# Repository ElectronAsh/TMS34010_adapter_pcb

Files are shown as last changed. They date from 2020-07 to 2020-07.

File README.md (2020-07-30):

# TMS34010_adapter_pcb

# USE AT YOUR OWN RISK!

This adapter PCB should allow you to connect a TMS34010 CPU to FPGA dev boards like the DE10 Nano, and maybe the DE0.

But it is currently UNTESTED, and does not include proper voltage translation buffers between 3V3 and 5V.

The current design only has some series resistors on each CPU output pin, with some clamp diodes on the FPGA GPIO headers.

There is an inherent risk of not using proper voltage translation, but I would personally risk it for short-term use for development.

If I get time, I will add proper voltage translation to the board.
The current design was just a way to get a quick version done for the few devs who might be able to make use of it.

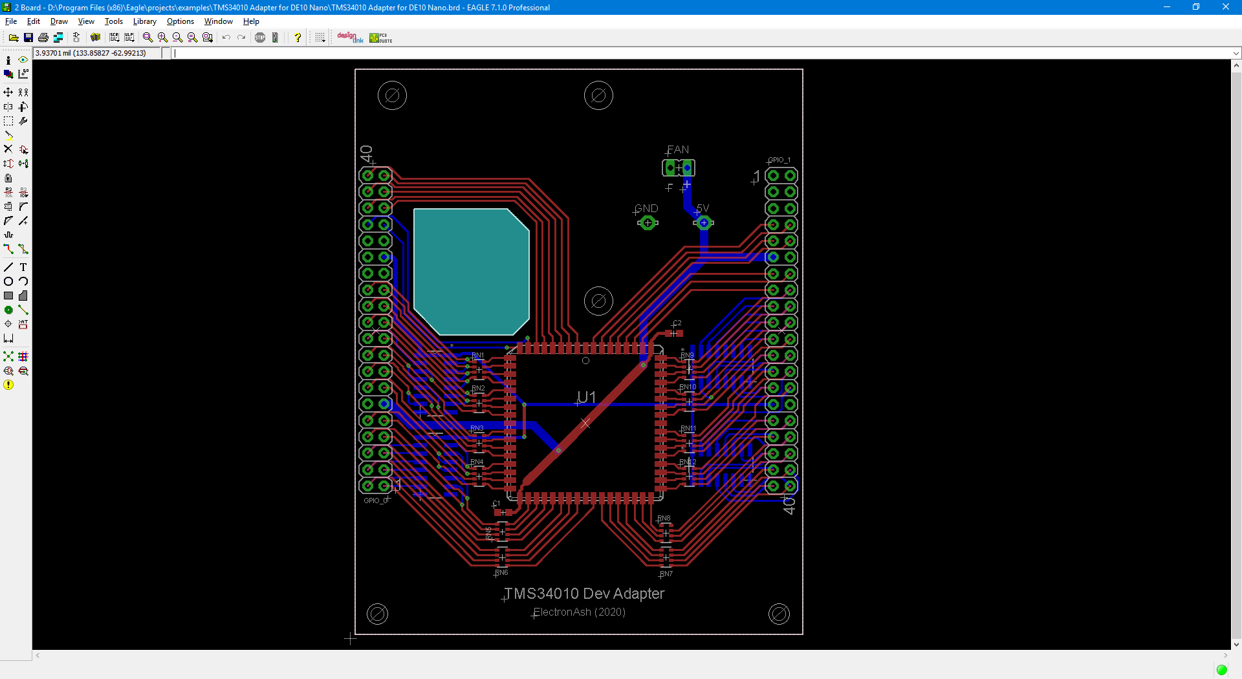
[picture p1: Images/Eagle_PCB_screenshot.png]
Eagle PCB screenshot


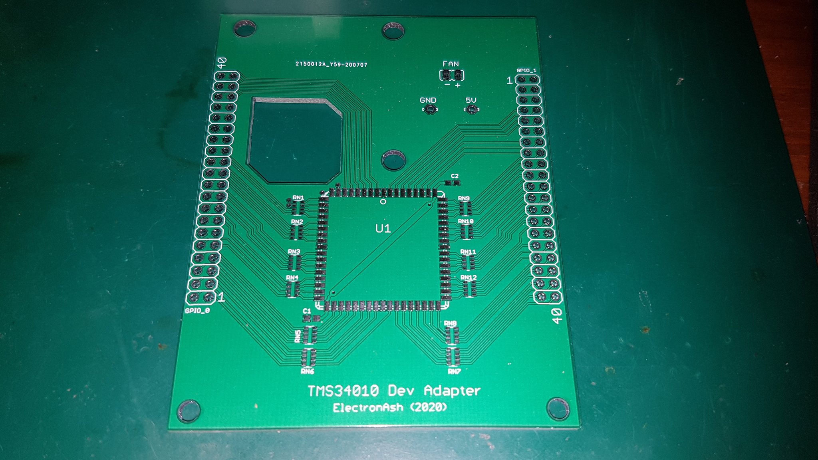
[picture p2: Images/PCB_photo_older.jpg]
PCB photo, older proto


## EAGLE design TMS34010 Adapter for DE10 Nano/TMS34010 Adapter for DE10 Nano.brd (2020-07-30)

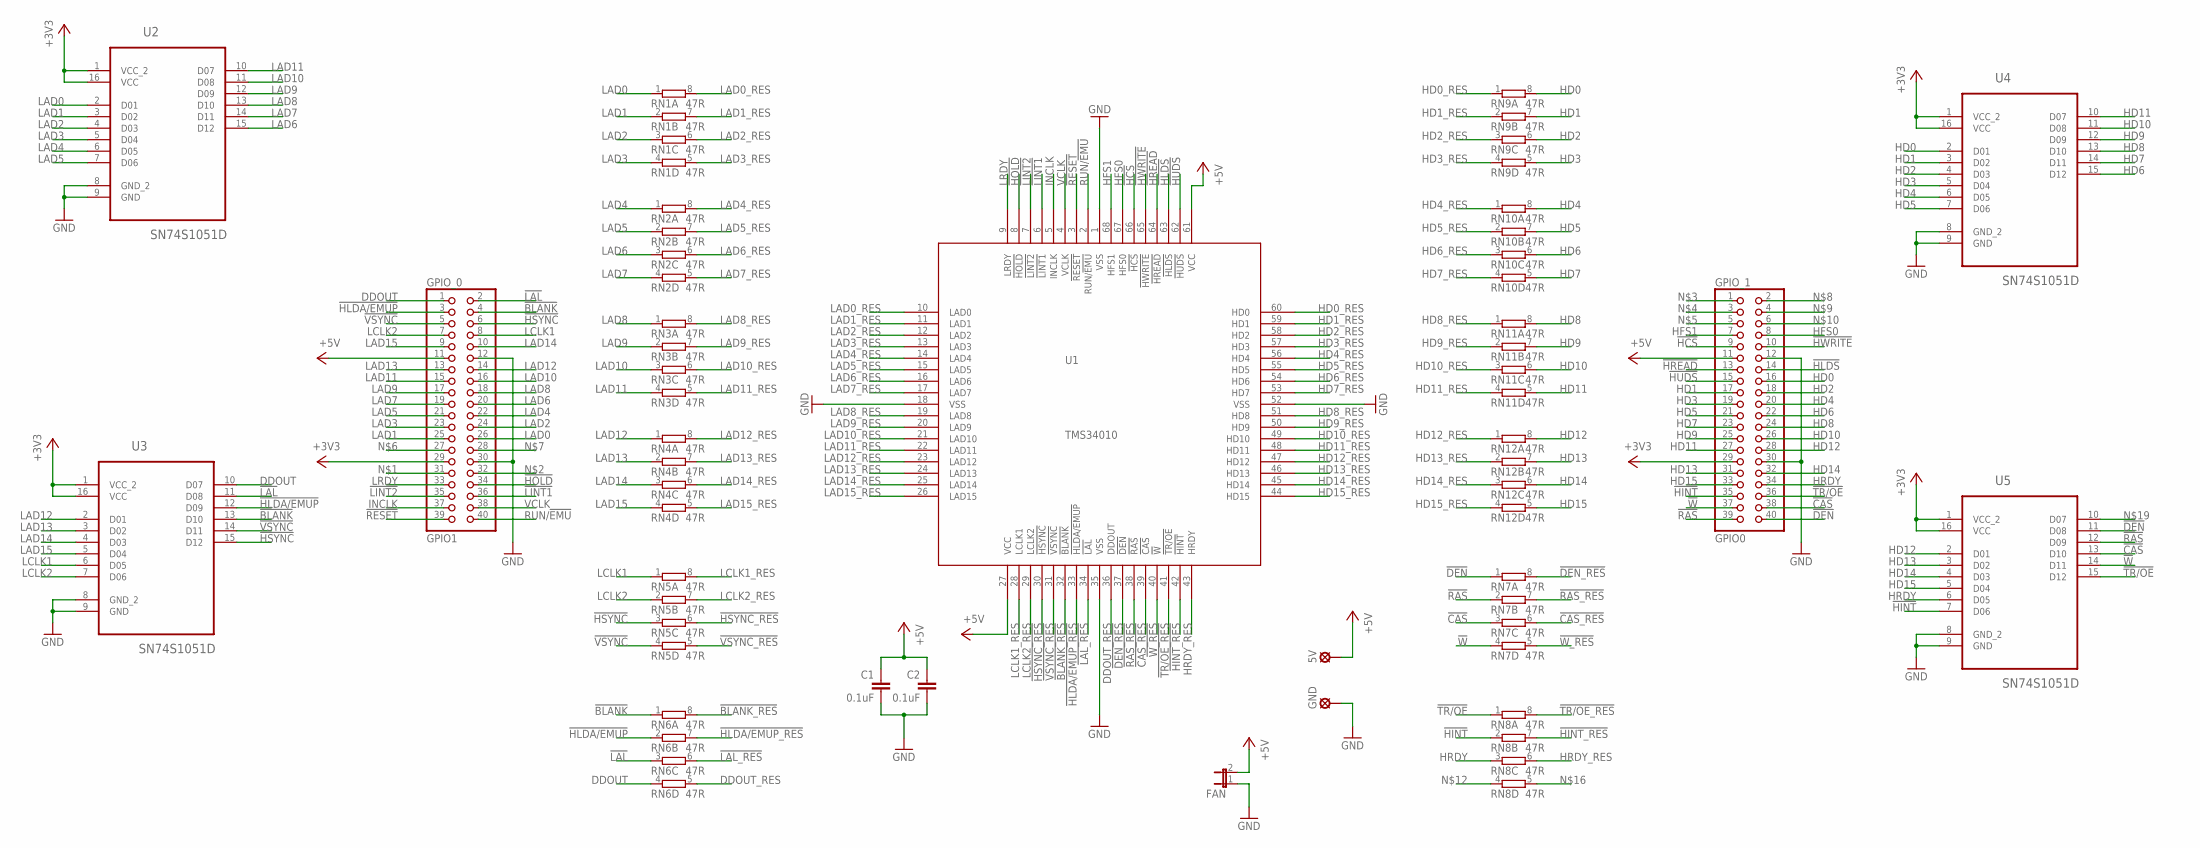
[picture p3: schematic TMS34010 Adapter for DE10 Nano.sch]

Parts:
5V: LSP13
C1, C2: 0.1uF; C0603
FAN: JP1E; JP1
GND: LSP13
GPIO_0: GPIO1; 2X20
GPIO_1: GPIO0; 2X20
RN1, RN2, RN3, RN4, RN5, RN6, RN7, RN8, RN9, RN10, RN11, RN12: 47R; EXBV8V
U1: TMS34010; PLCC68
U2, U3, U4, U5: SN74S1051D; SOIC127P600X175-16N

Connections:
!BLANK: GPIO_0.4, RN6.1, U3.13 (D10)
!BLANK_RES: RN6.8 (2), U1.32 (!BLANK)
!CAS: GPIO_1.38, RN7.3 (1), U5.13 (D10)
!CAS_RES: RN7.6 (2), U1.39 (!CAS)
!DEN: GPIO_1.40, RN7.1, U5.11 (D08)
!DEN_RES: RN7.8 (2), U1.37 (!DEN)
!HCS: GPIO_1.9, U1.66 (!HCS)
!HINT: GPIO_1.35, RN8.2 (1), U5.7 (D06)
!HINT_RES: RN8.7 (2), U1.42 (!HINT)
!HLDA/EMUP: GPIO_0.3, RN6.2 (1), U3.12 (D09)
!HLDA/EMUP_RES: RN6.7 (2), U1.33 (!HLDA/EMUP)
!HLDS: GPIO_1.14, U1.63 (!HLDS)
!HOLD: GPIO_0.34, U1.8 (!HOLD)
!HREAD: GPIO_1.13, U1.64 (!HREAD)
!HSYNC: GPIO_0.6, RN5.3 (1), U3.15 (D12)
!HSYNC_RES: RN5.6 (2), U1.30 (!HSYNC)
!HUDS: GPIO_1.15, U1.62 (!HUDS)
!HWRITE: GPIO_1.10, U1.65 (!HWRITE)
!LAL: GPIO_0.2, RN6.3 (1), U3.11 (D08)
!LAL_RES: RN6.6 (2), U1.34 (!LAL)
!LINT1: GPIO_0.36, U1.6 (!LINT1)
!LINT2: GPIO_0.35, U1.7 (!LINT2)
!RAS: GPIO_1.39, RN7.2 (1), U5.12 (D09)
!RAS_RES: RN7.7 (2), U1.38 (!RAS)
!RESET: GPIO_0.39, U1.3 (!RESET)
!TR/OE: GPIO_1.36, RN8.1, U5.15 (D12)
!TR/OE_RES: RN8.8 (2), U1.41 (!TR/OE)
!VSYNC: GPIO_0.5, RN5.4 (1), U3.14 (D11)
!VSYNC_RES: RN5.5 (2), U1.31 (!VSYNC)
!W: GPIO_1.37, RN7.4 (1), U5.14 (D11)
!W_RES: RN7.5 (2), U1.40 (!W)
+3V3: GPIO_0.29, GPIO_1.29, U2.1 (VCC_2), U2.16 (VCC), U3.1 (VCC_2), U3.16 (VCC), U4.1 (VCC_2), U4.16 (VCC), U5.1 (VCC_2), U5.16 (VCC)
+5V: 5V.MP, C1.1, C2.1, FAN.2, GPIO_0.11, GPIO_1.11, U1.27 (VCC), U1.61 (VCC)
DDOUT: GPIO_0.1, RN6.4 (1), U3.10 (D07)
DDOUT_RES: RN6.5 (2), U1.36 (DDOUT)
GND: C1.2, C2.2, FAN.1, GND.MP, GPIO_0.12, GPIO_0.30, GPIO_1.12, GPIO_1.30, U1.1 (VSS), U1.18 (VSS), U1.35 (VSS), U1.52 (VSS), U2.8 (GND_2), U2.9 (GND), U3.8 (GND_2), U3.9 (GND), U4.8 (GND_2), U4.9 (GND), U5.8 (GND_2), U5.9 (GND)
HD0: GPIO_1.16, RN9.8 (2), U4.2 (D01)
HD0_RES: RN9.1, U1.60 (HD0)
HD1: GPIO_1.17, RN9.7 (2), U4.3 (D02)
HD1_RES: RN9.2 (1), U1.59 (HD1)
HD2: GPIO_1.18, RN9.6 (2), U4.4 (D03)
HD2_RES: RN9.3 (1), U1.58 (HD2)
HD3: GPIO_1.19, RN9.5 (2), U4.5 (D04)
HD3_RES: RN9.4 (1), U1.57 (HD3)
HD4: GPIO_1.20, RN10.8 (2), U4.6 (D05)
HD4_RES: RN10.1, U1.56 (HD4)
HD5: GPIO_1.21, RN10.7 (2), U4.7 (D06)
HD5_RES: RN10.2 (1), U1.55 (HD5)
HD6: GPIO_1.22, RN10.6 (2), U4.15 (D12)
HD6_RES: RN10.3 (1), U1.54 (HD6)
HD7: GPIO_1.23, RN10.5 (2), U4.14 (D11)
HD7_RES: RN10.4 (1), U1.53 (HD7)
HD8: GPIO_1.24, RN11.8 (2), U4.13 (D10)
HD8_RES: RN11.1, U1.51 (HD8)
HD9: GPIO_1.25, RN11.7 (2), U4.12 (D09)
HD9_RES: RN11.2 (1), U1.50 (HD9)
HD10: GPIO_1.26, RN11.6 (2), U4.11 (D08)
HD10_RES: RN11.3 (1), U1.49 (HD10)
HD11: GPIO_1.27, RN11.5 (2), U4.10 (D07)
HD11_RES: RN11.4 (1), U1.48 (HD11)
HD12: GPIO_1.28, RN12.8 (2), U5.2 (D01)
HD12_RES: RN12.1, U1.47 (HD12)
HD13: GPIO_1.31, RN12.7 (2), U5.3 (D02)
HD13_RES: RN12.2 (1), U1.46 (HD13)
HD14: GPIO_1.32, RN12.6 (2), U5.4 (D03)
HD14_RES: RN12.3 (1), U1.45 (HD14)
HD15: GPIO_1.33, RN12.5 (2), U5.5 (D04)
HD15_RES: RN12.4 (1), U1.44 (HD15)
HFS0: GPIO_1.8, U1.67 (HFS0)
HFS1: GPIO_1.7, U1.68 (HFS1)
HRDY: GPIO_1.34, RN8.3 (1), U5.6 (D05)
HRDY_RES: RN8.6 (2), U1.43 (HRDY)
INCLK: GPIO_0.37, U1.5 (INCLK)
LAD0: GPIO_0.26, RN1.1, U2.2 (D01)
LAD0_RES: RN1.8 (2), U1.10 (LAD0)
LAD1: GPIO_0.25, RN1.2 (1), U2.3 (D02)
LAD1_RES: RN1.7 (2), U1.11 (LAD1)
LAD2: GPIO_0.24, RN1.3 (1), U2.4 (D03)
LAD2_RES: RN1.6 (2), U1.12 (LAD2)
LAD3: GPIO_0.23, RN1.4 (1), U2.5 (D04)
LAD3_RES: RN1.5 (2), U1.13 (LAD3)
LAD4: GPIO_0.22, RN2.1, U2.6 (D05)
LAD4_RES: RN2.8 (2), U1.14 (LAD4)
LAD5: GPIO_0.21, RN2.2 (1), U2.7 (D06)
LAD5_RES: RN2.7 (2), U1.15 (LAD5)
LAD6: GPIO_0.20, RN2.3 (1), U2.15 (D12)
LAD6_RES: RN2.6 (2), U1.16 (LAD6)
LAD7: GPIO_0.19, RN2.4 (1), U2.14 (D11)
LAD7_RES: RN2.5 (2), U1.17 (LAD7)
LAD8: GPIO_0.18, RN3.1, U2.13 (D10)
LAD8_RES: RN3.8 (2), U1.19 (LAD8)
LAD9: GPIO_0.17, RN3.2 (1), U2.12 (D09)
LAD9_RES: RN3.7 (2), U1.20 (LAD9)
LAD10: GPIO_0.16, RN3.3 (1), U2.11 (D08)
LAD10_RES: RN3.6 (2), U1.21 (LAD10)
LAD11: GPIO_0.15, RN3.4 (1), U2.10 (D07)
LAD11_RES: RN3.5 (2), U1.22 (LAD11)
LAD12: GPIO_0.14, RN4.1, U3.2 (D01)
LAD12_RES: RN4.8 (2), U1.23 (LAD12)
LAD13: GPIO_0.13, RN4.2 (1), U3.3 (D02)
LAD13_RES: RN4.7 (2), U1.24 (LAD13)
LAD14: GPIO_0.10, RN4.3 (1), U3.4 (D03)
LAD14_RES: RN4.6 (2), U1.25 (LAD14)
LAD15: GPIO_0.9, RN4.4 (1), U3.5 (D04)
LAD15_RES: RN4.5 (2), U1.26 (LAD15)
LCLK1: GPIO_0.8, RN5.1, U3.6 (D05)
LCLK1_RES: RN5.8 (2), U1.28 (LCLK1)
LCLK2: GPIO_0.7, RN5.2 (1), U3.7 (D06)
LCLK2_RES: RN5.7 (2), U1.29 (LCLK2)
LRDY: GPIO_0.33, U1.9 (LRDY)
RUN/!EMU: GPIO_0.40, U1.2 (RUN/!EMU)
VCLK: GPIO_0.38, U1.4 (VCLK)

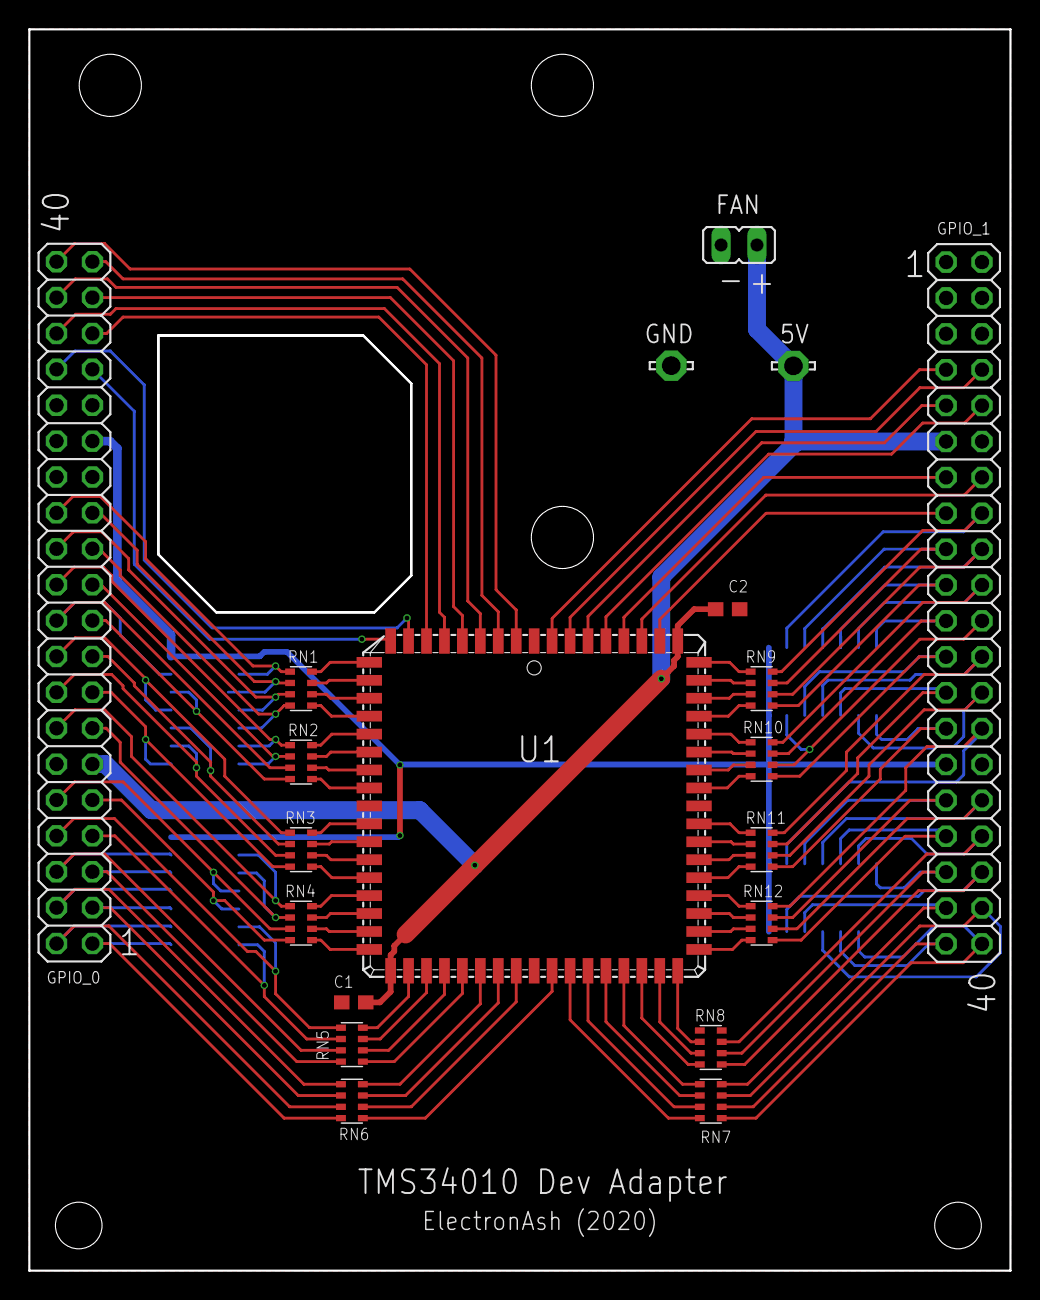
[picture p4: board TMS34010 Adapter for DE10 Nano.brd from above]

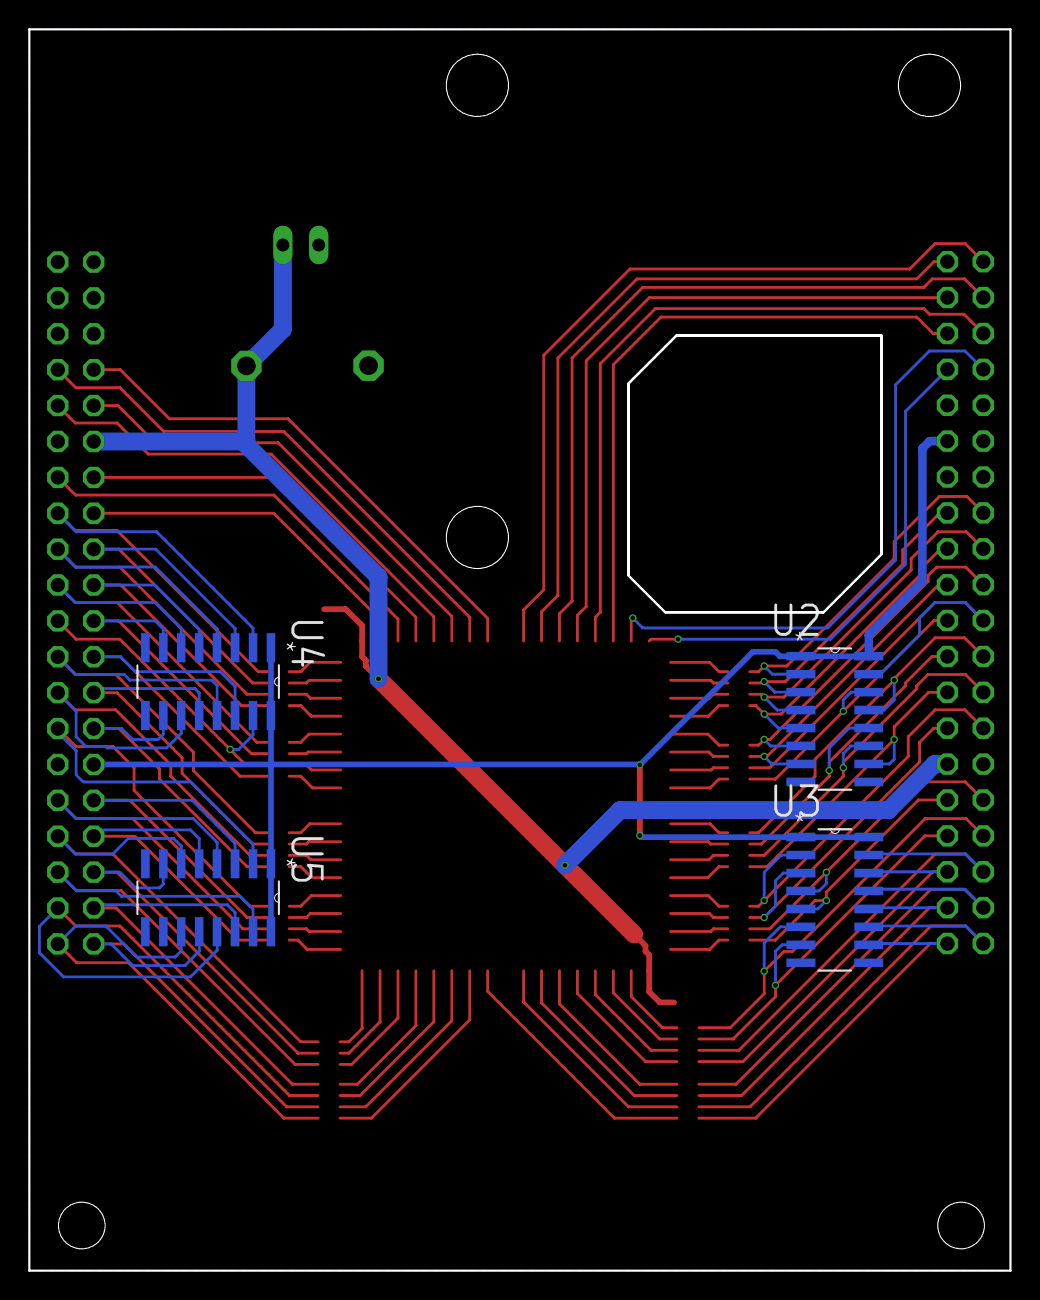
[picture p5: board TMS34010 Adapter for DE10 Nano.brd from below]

Board: 2 copper layers, 69.4 x 87.9 mm, 24 parts (4 on the bottom side), 112 nets.
